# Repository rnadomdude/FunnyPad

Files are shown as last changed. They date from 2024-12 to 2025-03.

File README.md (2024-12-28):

# FunnyPad
Yet another basic 17 key numpad with kailh hotswap sockets designed for fun.  
Made with the [nice!nano v2](https://nicekeyboards.com/docs/nice-nano/), but compatible with any Pro Micro boards.  
My first PCB, please leave feedback. 

CAD model  
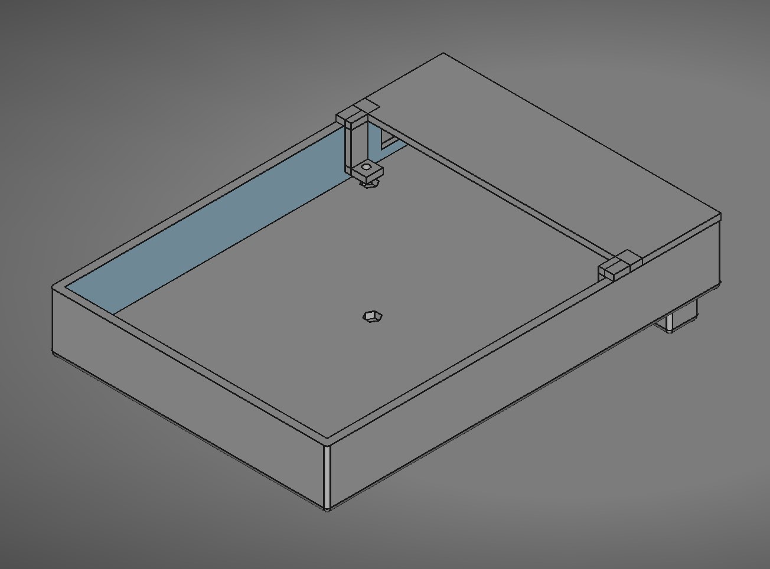
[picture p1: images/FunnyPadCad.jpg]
FunnyPadCad
  
Exploded  
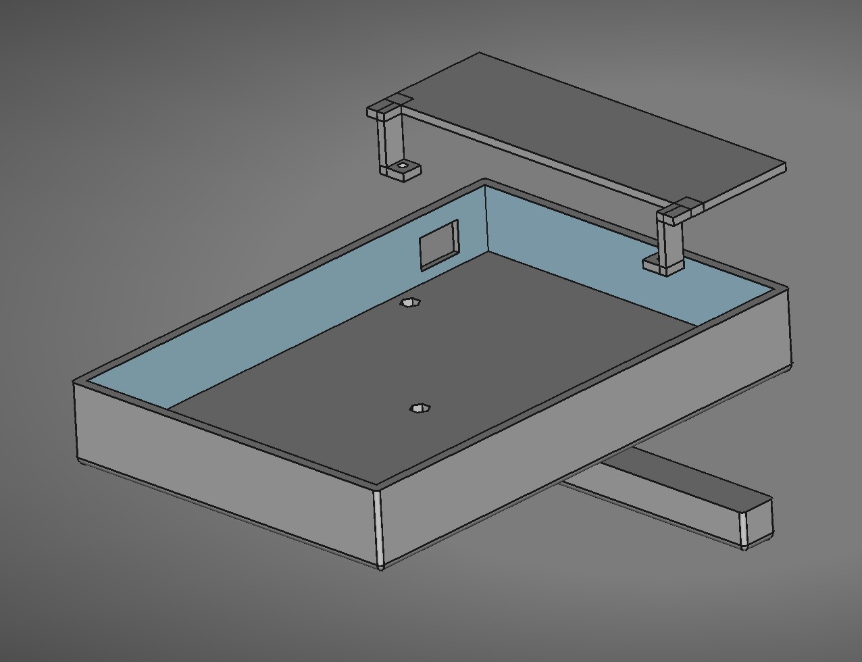
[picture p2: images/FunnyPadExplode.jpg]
FunnyPadExploded
  
Wireframe  
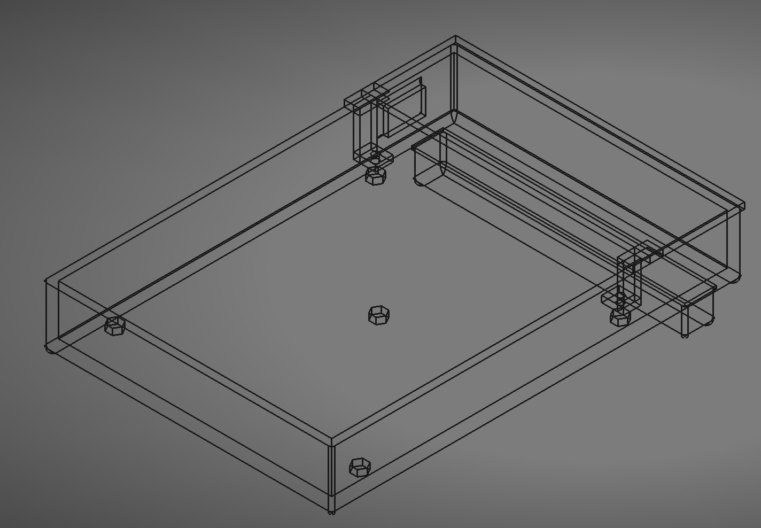
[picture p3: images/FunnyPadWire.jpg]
FunnyPadWireframe
  
PCB in kicad (2 layers)  
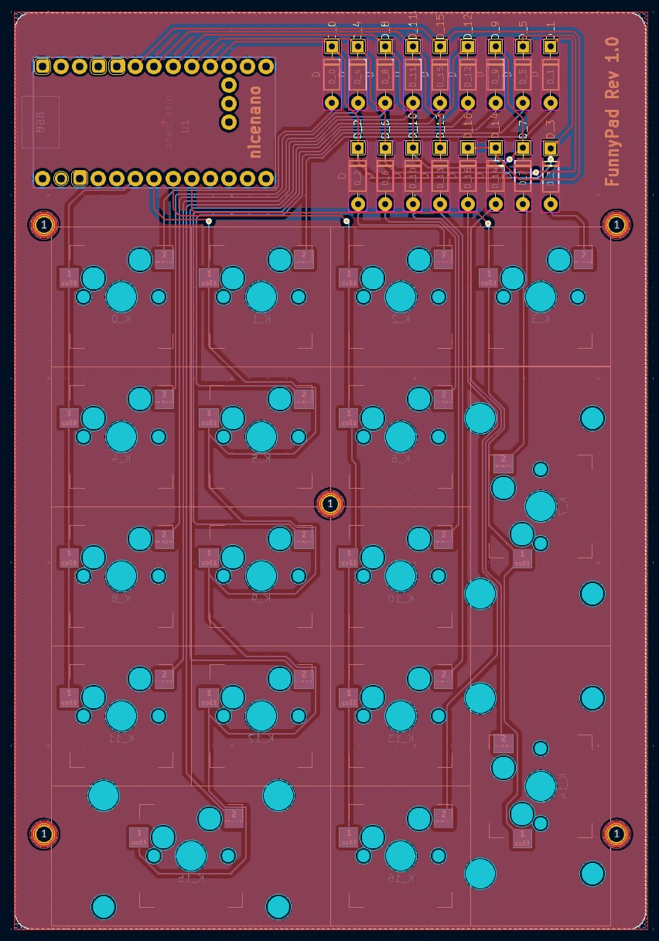
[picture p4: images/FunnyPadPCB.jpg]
FunnyPadPCB
  
Schematic  
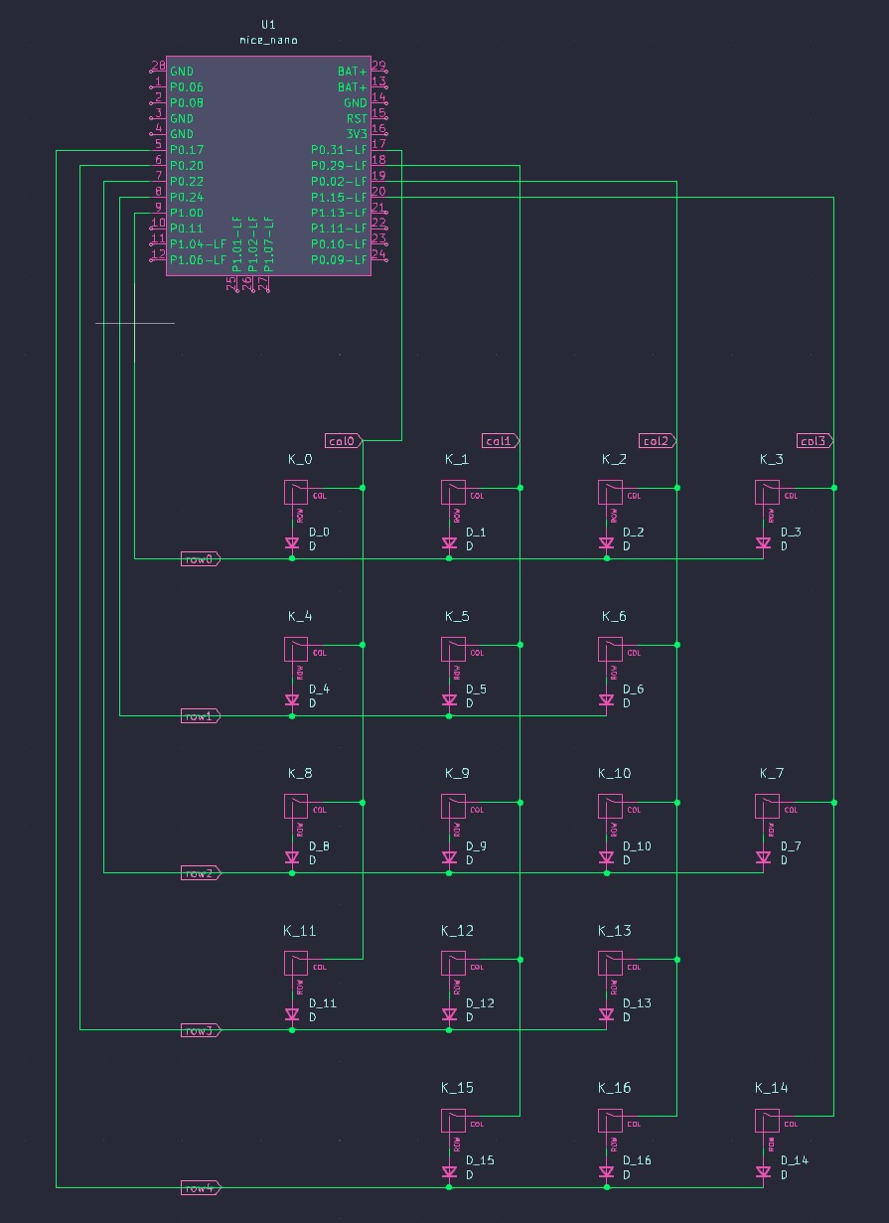
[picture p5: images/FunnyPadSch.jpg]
FunnyPadSch
  

## Features
- Wired/Bluetooth with rechargeable battery (as many mAh as you want!!!)
- Kailh hotswap sockets!!!
- I spent my free time on this
- Screw on stabilizers
- ZMK compatibility

## Parts required
- nice!nano v2 x1
- kailh hotswap sockets x17
- 1N4148 through hole diodes x17
- M2*5mm screws x3
- M2*8mm screws x2
- M2*5mm Hexagonal threaded spacers x5 
- 301230 3.7v 110mAh battery x1
- 2U screw on stabs x3
- Socket for nice!nano x1
- Switches of your choice x17

## Assembly

## References
- Made with KiCad8 and FreeCad
- Software done and compiled with github actions using [ZMK](https://zmk.dev/)
- Schematic and PCB partly generated from https://kb.xyz.is/ used in conjunction with https://www.keyboard-layout-editor.com/#/
- Nice!nano footprint from https://github.com/ebastler/marbastlib

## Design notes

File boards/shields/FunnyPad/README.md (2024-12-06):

# FunnyPad

I am losing it

## Board Revision and Layout Notes

Just a simple numpad

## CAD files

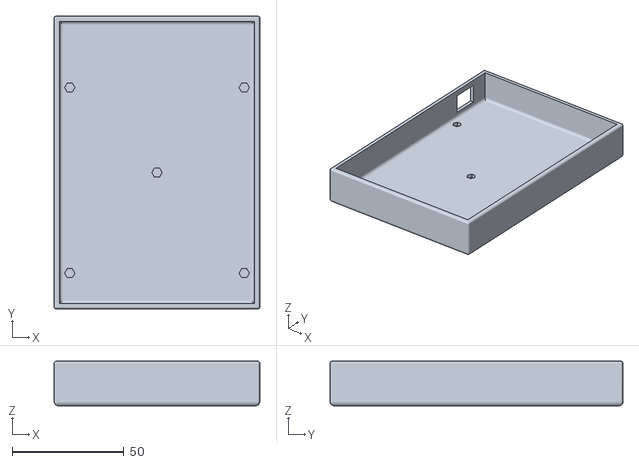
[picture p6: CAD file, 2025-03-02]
FunnyPad.stl
92.0 x 131.0 x 20.0

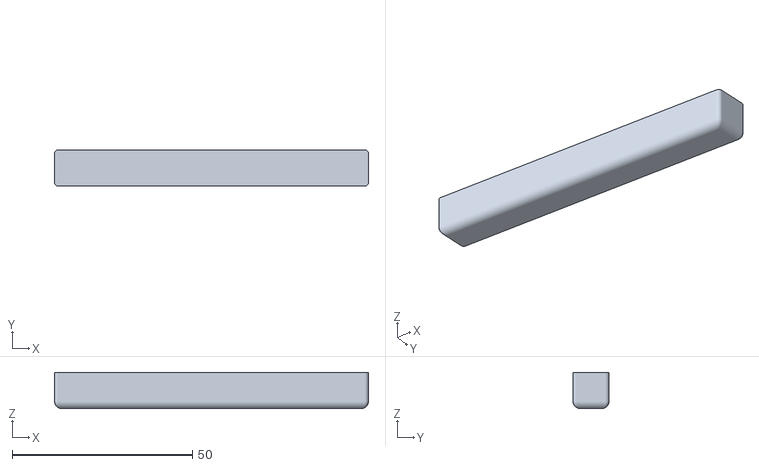
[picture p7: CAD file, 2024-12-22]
FunnyPad tented foot.stl
87.0 x 10.0 x 10.0

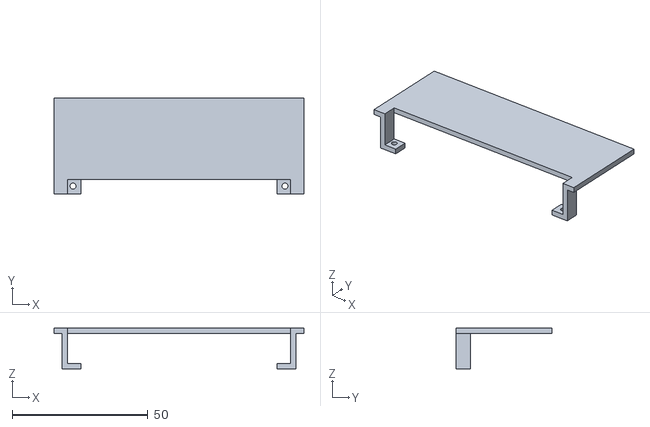
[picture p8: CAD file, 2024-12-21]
FunnyPad vanity plate.stl
92.0 x 35.5 x 15.0

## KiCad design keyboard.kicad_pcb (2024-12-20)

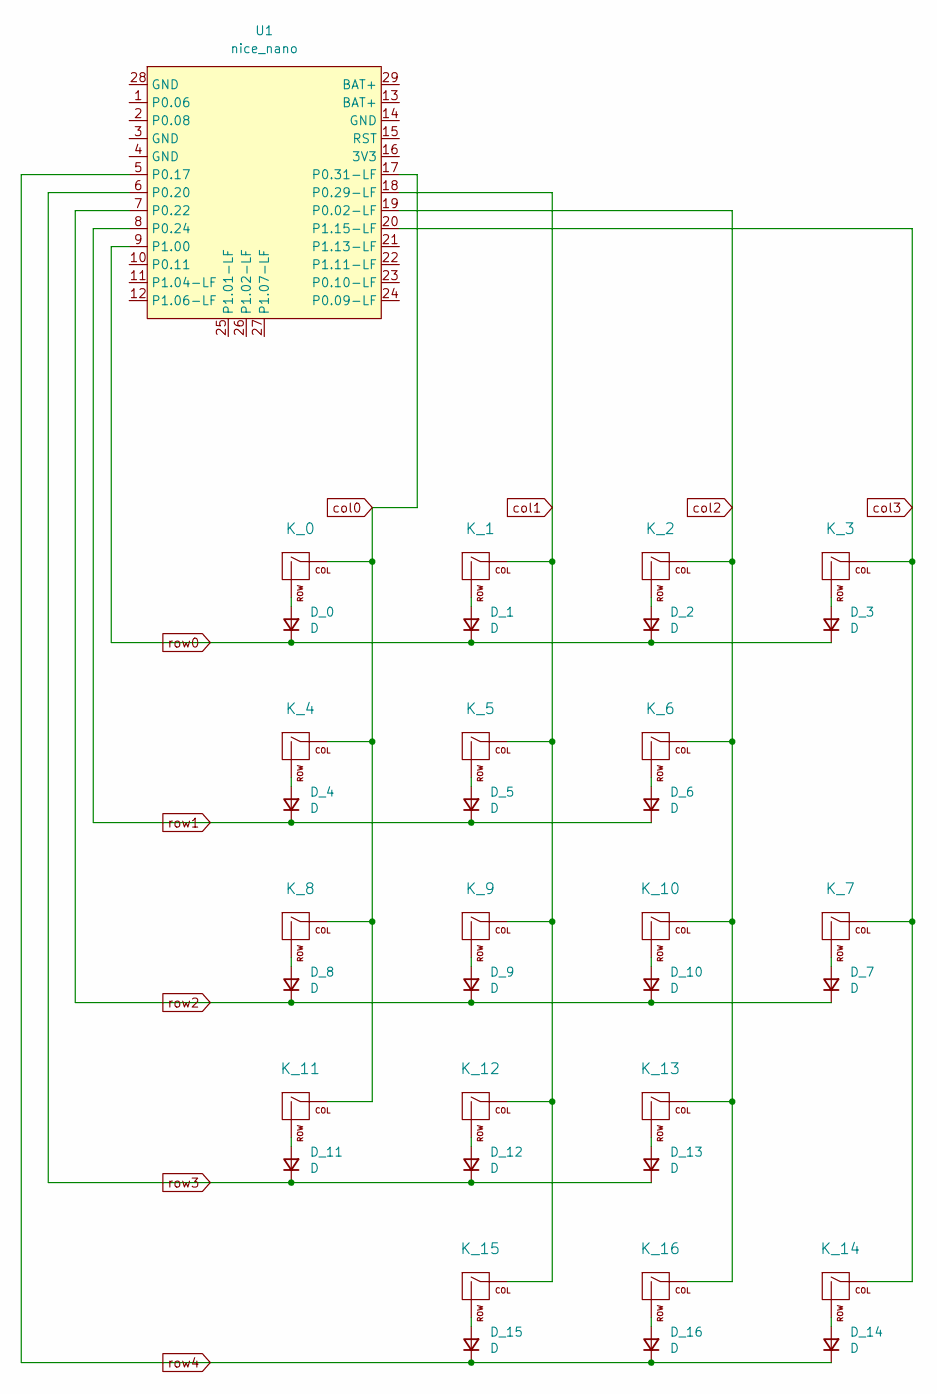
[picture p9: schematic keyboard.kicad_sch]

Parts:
D_0, D_1, D_2, D_3, D_4, D_5, D_6, D_7, D_8, D_9, D_10, D_11, D_12, D_13, D_14, D_15, D_16: D; D_SOD-123
K_0, K_1, K_2, K_3, K_4, K_5, K_6, K_7, K_8, K_9, K_10, K_11, K_12, K_13, K_14, K_16: KEYSW; MX-1U-NoLED
K_15: KEYSW; MX-2U-NoLED
U1: nice_nano; nice_nano_AH_USBup

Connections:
unnamed: D_0.2 (A), K_0.2 (ROW)
unnamed: D_1.2 (A), K_1.2 (ROW)
unnamed: D_2.2 (A), K_2.2 (ROW)
unnamed: D_3.2 (A), K_3.2 (ROW)
unnamed: D_4.2 (A), K_4.2 (ROW)
unnamed: D_5.2 (A), K_5.2 (ROW)
unnamed: D_6.2 (A), K_6.2 (ROW)
unnamed: D_7.2 (A), K_7.2 (ROW)
unnamed: D_8.2 (A), K_8.2 (ROW)
unnamed: D_9.2 (A), K_9.2 (ROW)
unnamed: D_10.2 (A), K_10.2 (ROW)
unnamed: D_11.2 (A), K_11.2 (ROW)
unnamed: D_12.2 (A), K_12.2 (ROW)
unnamed: D_13.2 (A), K_13.2 (ROW)
unnamed: D_14.2 (A), K_14.2 (ROW)
unnamed: D_15.2 (A), K_15.2 (ROW)
unnamed: D_16.2 (A), K_16.2 (ROW)
col0: K_0.1 (COL), K_4.1 (COL), K_8.1 (COL), K_11.1 (COL), U1.17 (P0.31-LF)
col1: K_1.1 (COL), K_5.1 (COL), K_9.1 (COL), K_12.1 (COL), K_15.1 (COL), U1.18 (P0.29-LF)
col2: K_2.1 (COL), K_6.1 (COL), K_10.1 (COL), K_13.1 (COL), K_16.1 (COL), U1.19 (P0.02-LF)
col3: K_3.1 (COL), K_7.1 (COL), K_14.1 (COL), U1.20 (P1.15-LF)
row0: D_0.1 (K), D_1.1 (K), D_2.1 (K), D_3.1 (K), U1.9 (P1.00)
row1: D_4.1 (K), D_5.1 (K), D_6.1 (K), U1.8 (P0.24)
row2: D_7.1 (K), D_8.1 (K), D_9.1 (K), D_10.1 (K), U1.7 (P0.22)
row3: D_11.1 (K), D_12.1 (K), D_13.1 (K), U1.6 (P0.20)
row4: D_14.1 (K), D_15.1 (K), D_16.1 (K), U1.5 (P0.17)

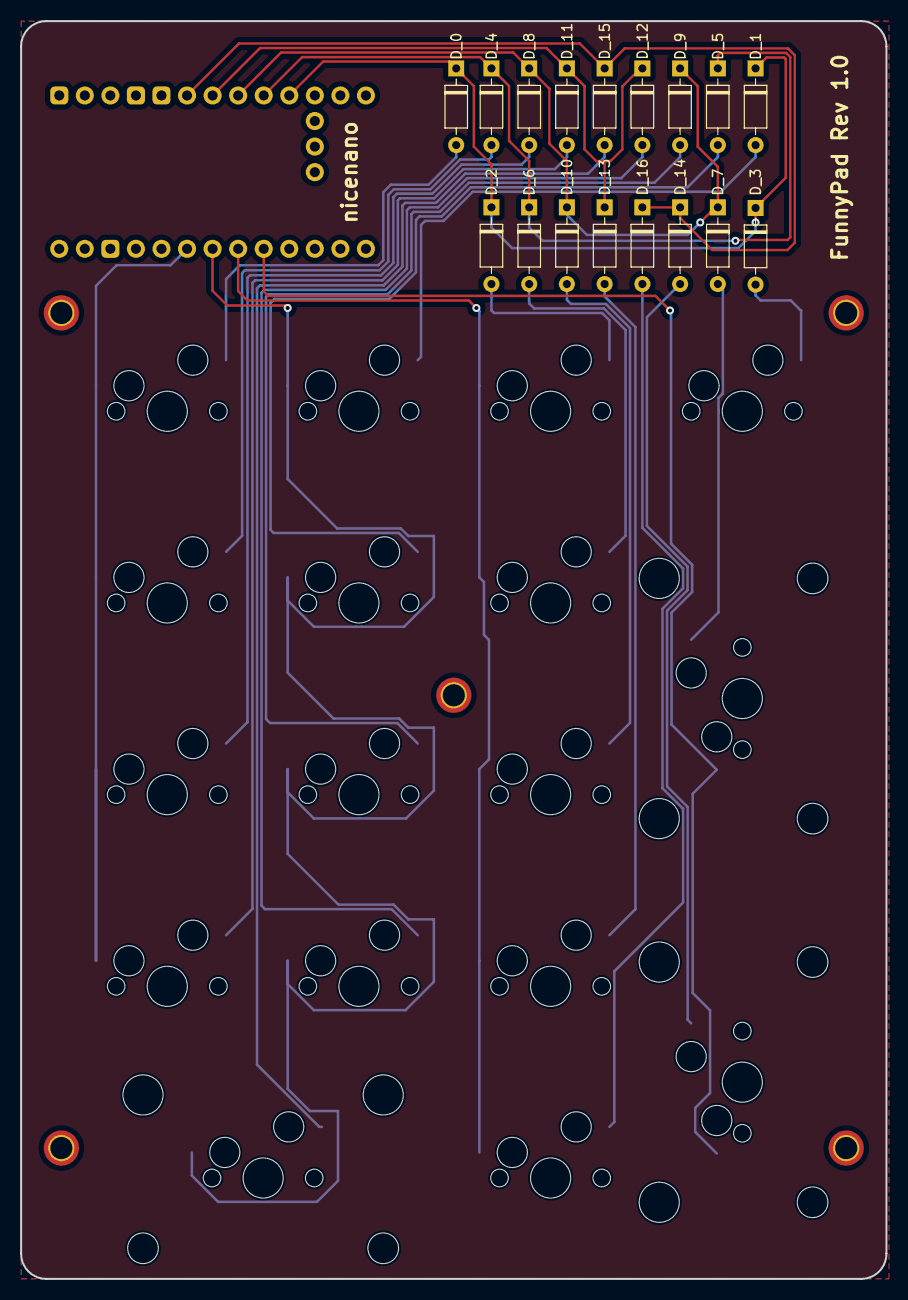
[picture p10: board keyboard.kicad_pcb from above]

Board: 2 copper layers, 86.0 x 125.0 mm, 40 parts (1 on the bottom side), 26 nets.

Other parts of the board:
M2_1, M2_2, M2_3, M2_4, M2_5: MountingHole_2.2mm_M2_ISO7380_Pad_TopBottom

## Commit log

2024-12-20 Update funnypad.overlay because of trace issues
2024-12-20 Gerber and drill files for PCB
    [keyboard-B_Cu.gbl, keyboard-B_Mask.gbs, keyboard-B_Paste.gbp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]
2024-12-20 KiCad files
    [keyboard.kicad_pcb, keyboard.kicad_sch]
2024-12-20 Measurement error fix
    [keyboard-B_Cu.gbl, keyboard-B_Mask.gbs, keyboard-B_Paste.gbp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]
2024-12-20 Adjusted M2 screw positions and board size
    [keyboard-B_Cu.gbl, keyboard-B_Mask.gbs, keyboard-B_Paste.gbp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]
2024-12-20 Adjusted M2 screw position and board size to 86*125mm
    [keyboard.kicad_pcb]
2024-12-21 Added STL files for keypad case
    [FunnyPad vanity plate.stl, FunnyPad.stl]
2024-12-22 Separated the foot and case for easier 3d printing
    [FunnyPad tented foot.stl, FunnyPad.stl]
2024-12-28 Added wireframe and exploded view
2025-03-02 Fixed foot fitting issue, usb cutout width, top edge fillet
    [FunnyPad.stl]
